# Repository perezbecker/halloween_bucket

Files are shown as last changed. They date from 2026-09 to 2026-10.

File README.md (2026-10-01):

# Cyclops Cauldron

A 3D-printed Halloween candy bucket with a sculpted skull, an animated
HalloWing eye behind a glass lens, and a rope handle. The skull prints
separately in white or glow PLA; the electronics sit behind a removable
battery cradle and candy guard.

The project includes parametric CAD, STEP and STL exports, editable print
plates, assembly illustrations, and audited G-code for a **Prusa CORE One+**.
All parts can be printed with a single nozzle and assembled with screws.

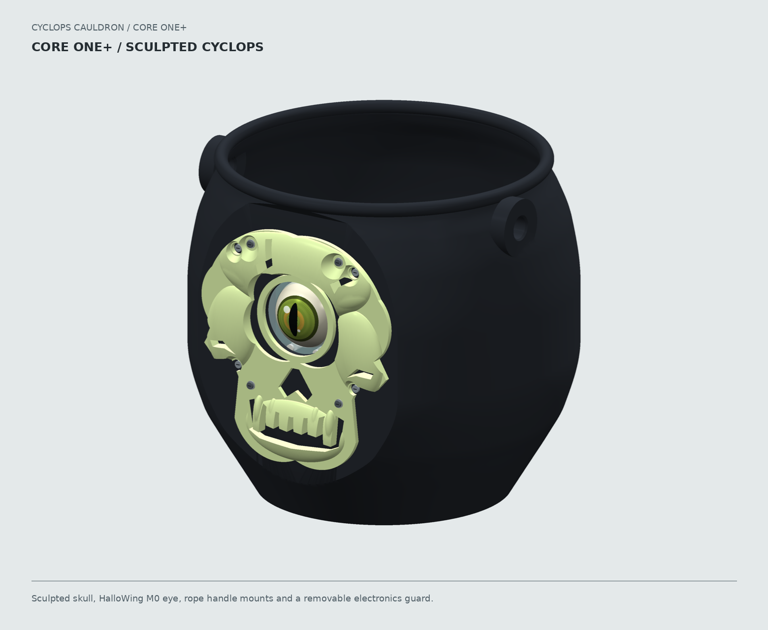
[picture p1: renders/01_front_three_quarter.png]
Assembled Cyclops Cauldron


**Build status:** the printed design has been reported to assemble and work
successfully. CAD and slicing checks also pass. Each builder should still
check their hardware fit and carrying strength; there is no certified load
rating or impact-resistance claim.

## Start Here

1. **Gather the hardware.** Use a HalloWing **M0**, its lens kit, and the
   fasteners in the [hardware list](docs/ASSEMBLY.md#hardware-list).
2. **Check your printer setup.** The supplied G-code requires the
   [CORE One+ configuration below](#printer-and-materials). For another setup,
   reslice the geometry with the appropriate printer and filament profiles.
3. **Print the small parts first.** Print the mounting test, one skull, and
   one carrier plus guard. The carrier and guard can share a plate.
4. **Fit-test the electronics.** Follow the
   [illustrated assembly guide](docs/ASSEMBLY.md#illustrated-assembly-sequence)
   and [fit-test procedure](docs/ASSEMBLY.md#fit-test-first).
5. **Print the cauldron and finish the build.** Transfer the tested parts,
   attach the rope, and complete the [hanging checks](docs/ASSEMBLY.md#rope-balance).

The mounting test is a small section of the bucket wall. It lets you check
the screws, lens alignment, PCB clearance and guard before the full bucket
print. The skull, carrier, guard and electronics used in the test are reused
in the finished bucket.

## What You Need

- Conventional PLA for the body, carrier, guard and mounting test; white PLA
  or suitable glow-in-the-dark PLA for the skull.
- Adafruit **HalloWing M0 #3900**, **40 mm glass lens #3853**, and
  **acrylic lens-holder kit #4013**.
- Adafruit **3.7 V, 500 mAh LiPo #1578**, a soft insulating pad and a
  hook-and-loop battery strap.
- **Eight M2 x 20**, **four M2 x 10**, and **four M2.5 x 20** machine screws,
  **12 M2 nuts**, **12 M2 washers**, and **four M2.5 insulating washers**.
  Keep the kit's four front M2.5 x 5 screws.
- Approximately **8-10 mm nylon sail rope** for the handle.

See the [complete bill of materials](docs/ASSEMBLY.md#hardware-list) for
washer dimensions, nut sizes and the purpose of each fastener. **M2 and M2.5
are different threads:** the bucket mounts use M2; the lens kit uses M2.5.

The eye runs on the HalloWing. This repository supplies the mechanical build,
not custom firmware; use the [electronics setup instructions](docs/ASSEMBLY.md#prepare-the-eye-electronics)
to check the eye demo before installing the board.

## Printer And Materials

Use the supplied G-code only when your setup matches:

| Requirement | Supplied configuration |
| --- | --- |
| Printer | Prusa CORE One+, single tool, without MMU or INDX |
| Nozzle | **0.4 mm high-flow**; wear-resistant/hardened for glow PLA |
| Filament | **1.75 mm PLA**, suitable for 220 C first layer / 215 C thereafter |
| Sheet / bed | Clean smooth PEI suitable for PLA, **60 C** |
| Firmware | Compatible with the official COREONE profile; jobs include notice **6.8.1+16182** |

Do not bypass printer or nozzle warnings. Standard-flow or different-diameter
nozzles, other printers, and other materials require reslicing. **Glow PETG is
not glow PLA** and must not use these files. Ordinary white PLA does not
require the glow job's abrasive-material setting.

Read the [printing guide](docs/PRINTING.md) and
[USB checklist](usb/COREONE_04HF_PLA/START_HERE.txt) before starting.

## Choose Your Print Jobs

For one complete build, choose **one skull material** and **one way to print
the carrier and guard**. Do not print both alternatives unless you want spares.

| Part or plate | G-code | Filament estimate | Time estimate |
| --- | --- | ---: | ---: |
| Mounting test | [01 Test](usb/COREONE_04HF_PLA/01_test_BLACK_04HF_PLA.gcode) | 37.27 g PLA | 1 h 47 m |
| Skull: white option | [02 White skull](usb/COREONE_04HF_PLA/02_skull_WHITE_04HF_PLA.gcode) | 64.17 g PLA | 4 h 52 m |
| Skull: glow option | [02 Glow skull](usb/COREONE_04HF_PLA/02_skull_GLOW_04HF_PLA.gcode) | 98.72 g glow PLA | 5 h 40 m |
| Carrier and guard together | [03+04 Combined](usb/COREONE_04HF_PLA/03_04_carrier_guard_BLACK_04HF_PLA.gcode) | 109.53 g PLA | 5 h 17 m |
| Carrier only | [03 Carrier](usb/COREONE_04HF_PLA/03_carrier_BLACK_04HF_PLA.gcode) | 26.20 g PLA | 1 h 32 m |
| Guard only | [04 Guard](usb/COREONE_04HF_PLA/04_guard_BLACK_04HF_PLA.gcode) | 83.38 g PLA | 3 h 44 m |
| Full bucket, after fit testing | [05 Cauldron](usb/COREONE_04HF_PLA/05_cauldron_BLACK_04HF_PLA.gcode) | 622.99 g PLA | 26 h 22 m |

The combined plate prints both parts **layer-by-layer**, not one complete
object at a time. It contains exactly the same carrier and guard as the
individual jobs. All jobs use one filament on extruder 1, with no purge tower
or mid-print colour changes.

With the combined plate, budget approximately **769.79 g for the body,
mounting test, carrier and guard**, plus **64.17 g white** or **98.72 g glow**
for the skull. Separate carrier/guard jobs bring the first total to 769.84 g.
These are slicer estimates including automatic startup purge, not measured
print weights. Leave extra filament for loading, retries and spares.

## Assembly

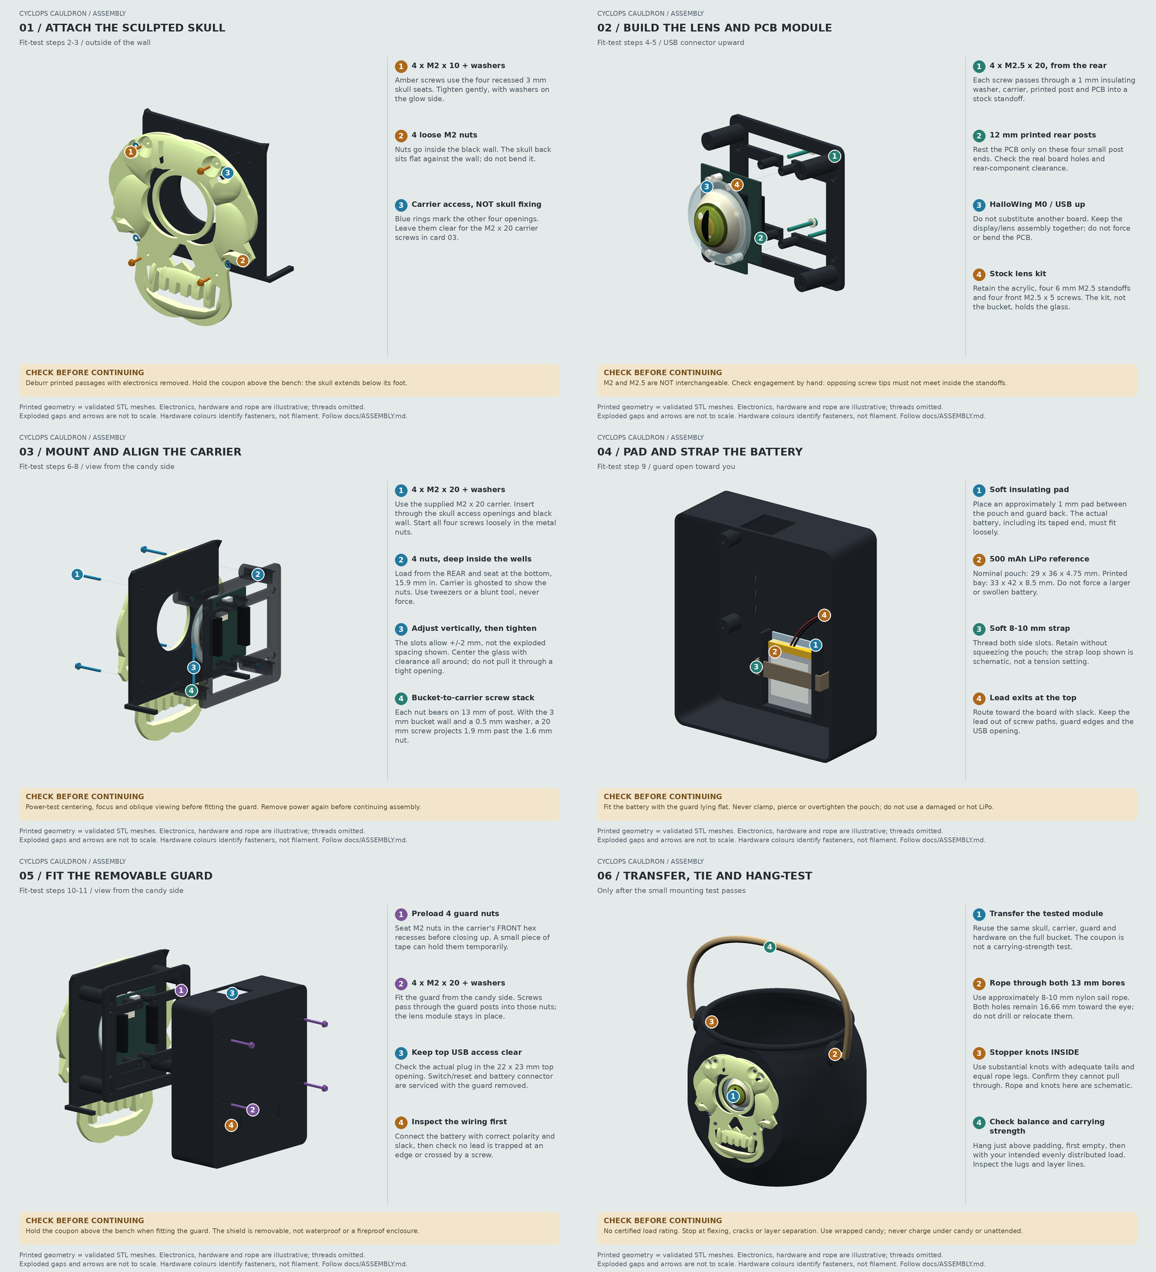
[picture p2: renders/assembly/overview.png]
Six illustrated assembly stages


The [assembly guide](docs/ASSEMBLY.md) covers mounting the skull, assembling
the lens/PCB module, aligning the carrier, securing the battery, fitting the
guard and attaching the rope.

- The skull attaches with **four M2 x 10 screws** and outside washers.
- The carrier attaches with **four M2 x 20 screws**. Seat its nuts at the
  bottoms of the **15.9 mm deep rear rectangular wells**, not at the openings.
- The PCB/lens module uses **four M2.5 x 20 screws with 1 mm insulating washers**.
  The stock acrylic kit retains the glass; the printed bezel does not clamp it.
- The guard attaches with the other **four M2 x 20 screws** and can be removed
  for battery and electronics access.

Use wrapped candy or a suitable liner. Check rope knots and printed anchors
over a padded surface before carrying a load. Protect the glass from impacts,
keep the electronics dry, and charge the LiPo under supervision with the
bucket empty and the guard removed. See [safe use and servicing](docs/ASSEMBLY.md#final-assembly-and-use).

## Design At A Glance

| Feature | Dimension |
| --- | --- |
| Printed body envelope | **224 x 209 x 200 mm** |
| Walls / floor | **3 mm nominal / 3.6 mm** |
| Rim / rope anchors | **8 mm rolled lip / 10 mm thick anchors** |
| Rope holes | **13 mm**, positioned toward the electronics |
| Sculpted skull | Approximately **128 x 138 mm**, up to **10.5 mm** thick |
| Skull screw seats / eye opening | **3 mm / 44.4 mm** |
| PCB rear-component clearance | **12 mm**, with **+/-2 mm** vertical eye adjustment |
| Battery bay | **33 x 42 x 8.5 mm** |

Explore the [design overview](renders/overview.png),
[exploded assembly](renders/07_exploded_mount.png),
[skull details](renders/faceplate_overview.png) and
[individual print-bed previews](renders/print_beds/overview.png).
Renders use the exported print meshes. Electronics, fasteners and optics are
illustrative; the green skull and glow study are not brightness predictions
or representations of white PLA.

## Editable Files And Project Layout

| Location | Contents |
| --- | --- |
| [print/](print/) | STL parts and placed geometry 3MFs, including the [combined carrier/guard plate](print/03_04_carrier_guard_black.3mf) |
| [cad/](cad/) | Individual STEP solids and the [assembled bucket](cad/assembled_bucket.step) |
| [design/](design/) | Parametric [bucket and mounting design](design/bucket.py) and [sculpted faceplate](design/sculpted_faceplate.py) |
| [usb/COREONE_04HF_PLA/](usb/COREONE_04HF_PLA/) | Ready-to-print jobs for the documented printer setup |
| [profiles/](profiles/) | Slicer settings and pinned profile provenance |
| [docs/](docs/) | Printing, assembly, mechanical sources and validation reports |
| [renders/](renders/) | Design views, assembly cards and print-bed illustrations |
| [tools/](tools/) and [tests/](tests/) | Export, slicing, rendering and validation tooling |

The skull geometry files use the name `bucket_glow` or
`02_skull_faceplate_glow.3mf`; **the same shape is used for white and glow PLA**.
Material selection belongs to the slicer profile. The geometry 3MFs can be
resliced for other supported setups; do not treat the supplied G-code as
printer-independent.

## Rebuild

You do not need the development tools to print the supplied jobs. For CAD,
slicer and render work, use Python 3.11 with the pinned
[dependencies](requirements.txt), CadQuery, PyVista/VTK and **PrusaSlicer 2.9.6**.
The rendering scripts use Linux DejaVu fonts. From the repository root on
Linux or WSL:

```sh
uv venv .venv --python 3.11
uv pip install --python .venv/bin/python -r requirements.txt
.venv/bin/python tools/build.py
.venv/bin/python tools/check_slicer.py --slicer /path/to/prusa-slicer-2.9.6
.venv/bin/python tools/check_slicer.py --white-skull --slicer /path/to/prusa-slicer-2.9.6
.venv/bin/python tools/check_slicer.py --carrier-guard --slicer /path/to/prusa-slicer-2.9.6
.venv/bin/python tools/render.py
.venv/bin/python tools/render_assembly.py
.venv/bin/python tools/render.py --print-beds
.venv/bin/python -m unittest discover -s tests
```

The build exports the carrier and assembled STEP, checks all parts, and
preserves the supplied body, skull, guard and coupon exports against
[pinned hashes](docs/printed_parts.json). The default slicer command
regenerates the individual carrier job and audits all five individual jobs;
the two flags generate the white skull and combined plate separately.
Render commands do not modify manufacturing files.

Each generated job is checked for native import, model bounds, tool
assignment, temperatures, flow, startup and shutdown. CAD checks cover solid
and mesh validity, mounting passages, collisions, clearances and material
budgets. These checks complement physical fitting; they do not certify
carrying strength, optical performance or every filament/printer combination.

See [mechanical sources and validation scope](docs/SOURCES.md) for dimensions,
assumptions, upstream credits and the detailed
[CAD](docs/validation.json), [individual-job](docs/slicer_validation.json),
[white-skull](docs/white_skull_validation.json) and
[combined-plate](docs/carrier_guard_validation.json) reports.

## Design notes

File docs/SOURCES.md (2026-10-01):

# Mechanical Sources And Assumptions

Checked against manufacturer pages and source files on **2026-09-25**.
Dimensions are millimeters. Source-derived dimensions are distinguished from
design clearances and unmeasured assembly assumptions.

This reference supports the [printing](PRINTING.md) and
[assembly](ASSEMBLY.md) guides. It explains where dimensions come from and
what the automated checks establish.

## Build Status And Validation Scope

The project owner has reported that the parts printed, assembled and worked
well. This is practical build feedback, not instrumented measurement of
material strength, optical performance or hardware tolerances.

The JSON validation reports record automated CAD, mesh, slicer and G-code
checks. Their limitations describe the scope of those runs; physical build
feedback is recorded here separately. No certified carrying-load rating,
impact rating or food-contact suitability is provided.

## Manufacturer References

| Part | Source facts used | Reference |
| --- | --- | --- |
| HalloWing M0, #3900 | Nominal 60 x 51 x 11 envelope; rear LiPo/USB ports; USB upward | [Guide](https://learn.adafruit.com/adafruit-hallowing/overview), [product](https://www.adafruit.com/product/3900), [downloads](https://learn.adafruit.com/adafruit-hallowing/downloads) |
| LiPo #1578 | 29 x 36 x 4.75; 102 mm lead; 500 mAh, 3.7 V nominal | [Adafruit battery](https://www.adafruit.com/product/1578) |
| Glass lens #3853 | 40 outer diameter, 37.5 inner/dome diameter, 16 height, 22 focal length; lip-edge retained by holder | [Adafruit lens](https://www.adafruit.com/product/3853) |
| Lens holder #4013 | 52.3 x 50 x 2.8 nominal; eight M2.5 x 5 screws and four M2.5 x 6 F-F spacers | [Adafruit kit](https://www.adafruit.com/product/4013) |
| Lens assembly | Acrylic and PCB joined by four nylon M2.5 spacers and eight screws | [Adafruit assembly guide](https://learn.adafruit.com/hallowing-all-seeing-skull/build-the-all-seeing-skull) |
| Prusa CORE One+ | 250 x 220 x 270 build volume; one nozzle without MMU/INDX | [Prusa CORE One+](https://www.prusa3d.com/product/prusa-core-one/) |

The battery listing notes a folded/taped cable-end change from June 2022. The
cradle therefore has more room than the nominal pouch dimensions and uses a
soft strap rather than a tight clip. Check your particular battery, including
its end seal and cable fold; the cavity is not permission to use a swollen cell.

## Verified Hole Geometry

Source repository: [Adafruit-Hallowing-M0-PCB](https://github.com/adafruit/Adafruit-Hallowing-M0-PCB),
pinned at commit `c0585b0672ce13e163b8da6ce9215ec600c63d64`.

The Eagle board contains two plain 2.54 mm lower lens holes at
`(X,Y) = (+/-8.89, -18.161)` and two plated 2.5 mm upper lens holes at
`(+/-8.89, +27.559)`. Thus the pitch is **17.78 x 45.72**. The two larger
3.175 mm lanyard holes at `(+/-17.145, +22.86)` are **not** used by this design.

The lens-holder Illustrator file is a PDF-compatible vector drawing. Reading
its actual hole subpaths gives the same 17.78 x 45.72 pitch. Its central lens
circle maps to approximately `Eagle Y = 3.082925`, which is **1.616075 mm below**
the four-hole pattern's midpoint. The model uses that center, with +/-2 mm
vertical adjustment through the bucket's separate M2 carrier fasteners.

The historical vector drawing's aperture is approximately **36 mm**, while the
current glass listing mentions a **38 mm mounting cutout**; its outside outline
also differs slightly from the current kit's nominal dimensions. Accordingly,
**this project does not recreate or replace the acrylic retainer**. It reuses
the purchased kit and provides a 44.4 mm clearance opening in the bucket for the
40 mm lens. Validate the actual kit revision on the coupon.

The manufacturer notes an October 2023 PCB silkscreen/connector update; the
published mechanical source is older. No claim is made that a later unmeasured
revision is mechanically identical. The M0 hardware must pass the fit test.

The structured measurements, source hashes, connector locations, and PCB outline
are recorded in [hardware_reference.json](hardware_reference.json). The original
board and acrylic design are by **Limor Fried/Ladyada for Adafruit Industries**;
their source repository publishes them under Creative Commons Attribution/Share-Alike.
See its [license](https://github.com/adafruit/Adafruit-Hallowing-M0-PCB/blob/master/license.txt).
The bucket and cyclops skull artwork are drawn for this project, not copied
from a third-party printable model. Manufacturer source files remain in an ignored cache,
not in the distributed manufacturing files.

To reproduce the source measurements from the repository root:

```sh
curl --fail --location --create-dirs 'https://raw.githubusercontent.com/adafruit/Adafruit-Hallowing-M0-PCB/c0585b0672ce13e163b8da6ce9215ec600c63d64/Adafruit%20Hallowing%20M0%20Express.brd' -o .cache/hallowing.brd
curl --fail --location --create-dirs 'https://raw.githubusercontent.com/adafruit/Adafruit-Hallowing-M0-PCB/c0585b0672ce13e163b8da6ce9215ec600c63d64/HalloWing%20Lens%20Holder.ai' -o .cache/lens-holder.ai
.venv/bin/python tools/inspect_hardware.py .cache/hallowing.brd --lens .cache/lens-holder.ai --output docs/hardware_reference.json
```

## Design Clearances And Checks

- PCB thickness **1.6**, rear support height **12**, and a **1 mm insulating
  washer** are stack-up assumptions/design choices. Confirm actual thicknesses,
  component heights, and that the opposing M2.5 screw tips do not bottom out.
- The assembly has generous lateral clearance for the approximately 52 mm
  acrylic, PCB, and rear headers. The USB top throat is **22 x 23**, not a
  manufacturer-specified USB plug envelope. Try your actual plug before printing
  the full bucket. The switch/reset require removing the candy guard.
- The glass's complete lip cross-section and assembled focal behavior were not
  measured. The hole clears its full outer diameter; the purchased kit sets the
  display-to-lens spacing. Do not interpret the textured render dome as an
  optical simulation.
- Printed M2 and M2.5 clearances are **2.4** and **2.9** respectively. Guard M2
  nut recesses allow approximately **4.3 across flats / 1.8 deep**. The four
  bucket-side sliding wells are **4.3 wide x 8.8 high x 15.9 deep**, open from
  the carrier rear. They place the nut bearing faces at
  Y = **-73**, leaving **13 mm** of post toward the wall. A **20 mm M2** screw,
  0.5 mm washer, 3 mm wall and 1.6 mm nut leave **1.9 mm** of tip beyond the
  nut, inside the well. These are FDM fit allowances and nominal hardware
  assumptions, not measured tolerances or a strength certification.
- Battery space is **33 W x 42 H x 8.5 D**. The cell requires a soft pad,
  noncompressive strap, lead slack, and inspection before each use.
- Rope anchors are modeled 10 thick around 13 bores, tied into the black wall
  below the rolled rim. Their common Y = -16.66 axis offsets the handle toward
  the electronics. The balance calculation reports tilt about that modeled
  axis. **No FEA, instrumented drop/creep results, or certified carrying-load
  rating** is provided. Evaluate printed layer adhesion and rope abrasion.
- Density limits of **1.30 g/cm3 black / 2.00 g/cm3 glow** are conservative
  budgeting assumptions, not specifications for an unspecified filament brand.
  Actual slicing and manufacturing still control spool use.

## Cauldron Balance Assumptions

The cauldron has a 224 mm belly, 200 mm height, 186 mm neck diameter,
8 mm rolled lip, and 146 mm flat base. The flat electronics face is at Y = -89
and the eye at Z = 125. The skull has raised forehead, brow, cheek, jaw and tooth
contours, up to **10.5 mm total thickness**, over a flat **3 mm mounting layer**.
Recessed 8.4 mm diameter screw-seat lands accept **M2 x 10** fasteners.
The eye bezel is flat inside a 52.4 mm diameter keep-clear zone, with a
44.4 mm bore and separate carrier-screw access holes. The body wall has full
thickness behind the skull except for the eye and fastener openings.

Nominal balancing uses black/glow densities of 1.24/1.50 g/cm3. PCB and battery
masses come from Adafruit; the glass is **estimated at 31 g** from its approximate
glass-cap envelope, not a measured product weight. The acrylic/kit (5 g), extra
carrier/guard fasteners (12 g), skull fasteners (3 g), strap/pad (3 g), and
component mass centers are estimates, not measured assembly weights.
See [assembly and balance](ASSEMBLY.md#rope-balance) for the complete assumptions,
centered-candy scenarios, density/lens sensitivity, and required hanging test.

For a glow skull, the computed nominal assembly mass is **864.9 g**, with a
center near (0, -19.44, 100.59). The bore centers are
(+/-99.33, -16.66, 178), giving about **2.1 degrees of empty forward tilt**.
Both lug material and removed hole material are included; the coupon and
discarded supports are excluded. A symmetric rope is assumed. Unequal knots,
an off-center grip and uneven candy are not modeled. A conventional white
skull has a different mass, so its balance must be checked on the actual build.

## Digital Verification

[validation.json](validation.json) records valid CAD solids, watertight,
consistently wound meshes, volumes, bed envelopes, nonintersecting material
volumes, mounting/candy-guard clearances, fastener passages, and the coupon's
identity to the corresponding cauldron geometry. The black body and separate
sculpted glow faceplate are individually connected, nonintersecting solids. Four
additional screw bores, washer-bearing lands, and clearance for internal M2
hardware are checked. The actual faceplate is reused for the black coupon test.
The saved cauldron, carrier and guard STEP files are checked directly for
faceplate intersections. The skull has a complete 3 mm mounting layer with
outward relief. [printed_parts.json](printed_parts.json) pins sixteen
compatibility-critical cauldron, skull, guard and coupon CAD, STL, 3MF and
G-code files. The default build regenerates the carrier and verifies and reuses
those supplied exports. The individual and combined plates contain the same
carrier. Checks cover its interfaces, nominal M2 x 20 engagement, nut bearing
area and insertion paths at the center and both ends of the +/-2 mm adjustment.

Mass calculations use adaptive, spline-span CAD integration and are checked
against fine triangle meshes for both volume and centroid agreement. The
cauldron profile uses local cubic segments to avoid unstable section Booleans
on a single long interpolated surface. Checks require the coupon to retain a
complete wall, clear rope bores on the fixed printed axis, uninterrupted lug bearing
rings, and support-critical bowl/neck slopes above 55 degrees.

The [individual-job report](slicer_validation.json) covers native
**PrusaSlicer 2.9.6** imports, per-object bounds and extruder **1 only** for the
five single-part plates. The [white-skull report](white_skull_validation.json)
and [combined-plate report](carrier_guard_validation.json) track their own
inputs and outputs. The combined job also verifies both parts' extrusion on
every shared layer, resolving the slicer's object IDs by their names.

The G-code audit examines executable commands as well as settings, checking
model/nozzle/firmware notices, cleaning, levelling, single-nozzle use, PLA
temperatures, flow, model-phase moves and heater shutdown. Four negative tests
inject an extra tool, an out-of-bed move, overtemperature and missing mesh
activation; all must be rejected. Regression tests cover object-order changes,
invalid layer sequences and ownership of the separate validation manifests.

## Official Machine Profile

Source: [PrusaSlicer-settings-prusa-fff](https://github.com/prusa3d/PrusaSlicer-settings-prusa-fff),
commit `65c5c8f1e1c3836f306119c49d717759cbc368db`, bundle **PrusaResearch 2.5.10**.
The [pinned bundle](https://raw.githubusercontent.com/prusa3d/PrusaSlicer-settings-prusa-fff/65c5c8f1e1c3836f306119c49d717759cbc368db/PrusaResearch/2.5.10.ini)
and [PrusaSlicer 2.9.6 release](https://github.com/prusa3d/PrusaSlicer/releases/tag/version_2.9.6)
are the reproducible inputs. The executable used here is the official portable
Windows 2.9.6 build through WSL interop. The scripts also accept a native 2.9.6
executable through `--slicer`.

Profiles are resolved from **Prusa CORE One HF0.4 nozzle**, **0.20mm STRUCTURAL
@COREONE 0.4**, and **Generic PLA @COREONE HF0.4**. The official `start_gcode`
and `end_gcode` are preserved byte-for-byte at the configuration level. The
printer script emits COREONE identification, 0.4 mm high-flow nozzle checks,
the 6.8.1+16182 firmware notice, cleaning, mesh probing, chamber control, purge,
and parking. The glow profile sets `filament_abrasive=1`, activating the
firmware's abrasive/nozzle check. The original startup purge intentionally uses
Y = -2.5; model-phase motion is separately checked against the 250 x 220 bed.

Derived base settings use seven walls, 0.20 mm layers, conservative 6/3 mm3/s
conventional/glow flow limits, and **220/215 C nozzle, 60 C bed** PLA temperatures.
The sculpted faceplate overrides layer height to **0.10 mm** (0.20 mm first),
uses **100% rectilinear** infill and ten top/bottom solid layers, without supports
or a brim. The white skull uses conventional PLA with a 6 mm3/s limit and no
abrasive-material flag; glow uses 3 mm3/s and the abrasive check. These are
documented operating requirements, not approval for every filament brand. Full
configuration files and input/output hashes are in
[profiles/provenance.json](../profiles/provenance.json). Prusa profile authors
and licensing remain with their source repositories.

The G-code targets the documented **CORE One+ / 0.4 mm high-flow / PLA /
smooth PEI** setup, with a wear-resistant nozzle additionally required for
glow. It is **not universal across CORE One+ configurations**. Each builder
must verify the setup and observe the print rather than bypassing warnings.
The export and audit tools do not connect to a printer or change its firmware.

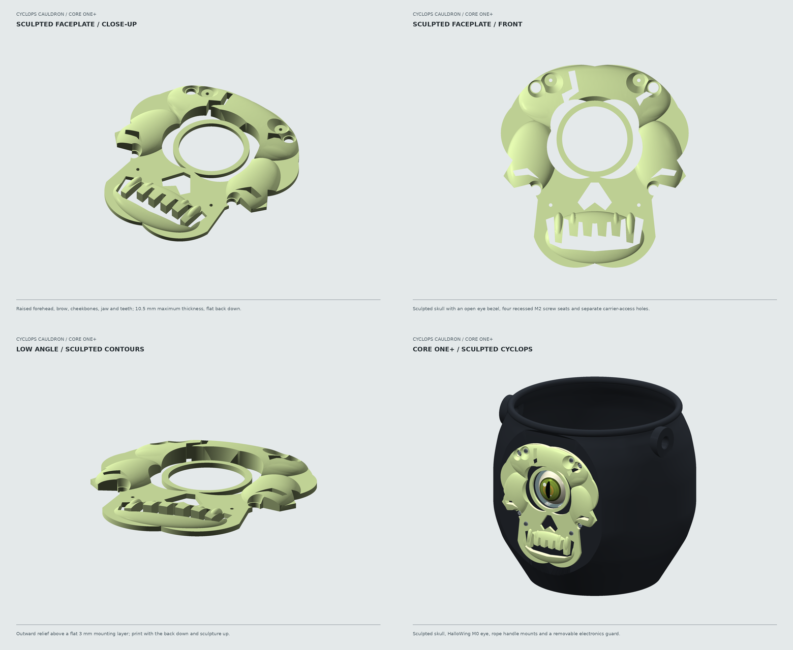
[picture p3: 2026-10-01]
renders/faceplate_overview.png

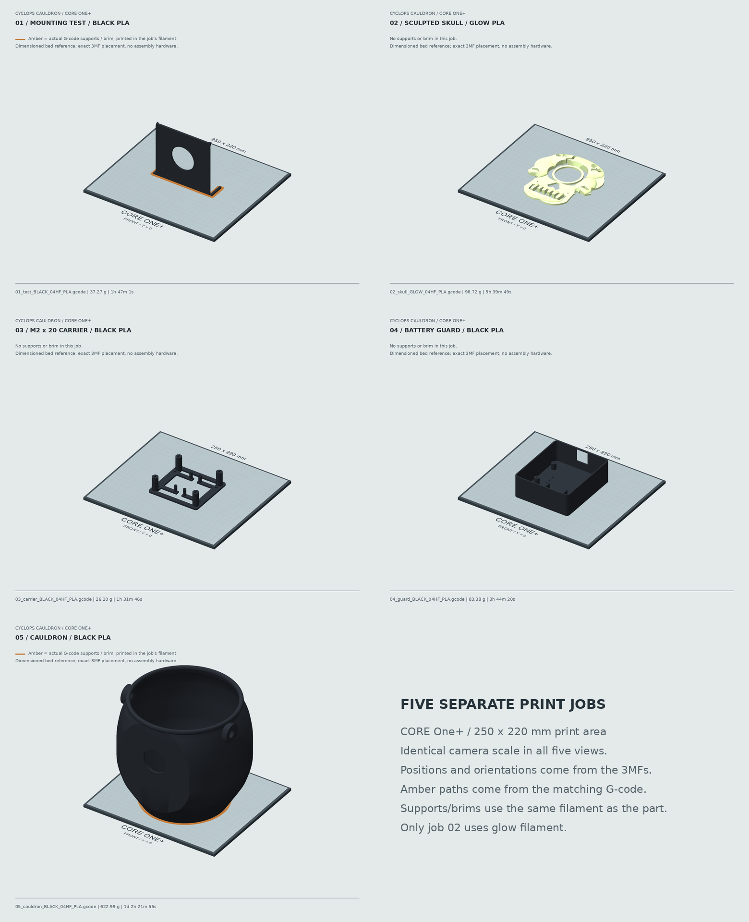
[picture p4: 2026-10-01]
renders/print_beds/overview.png

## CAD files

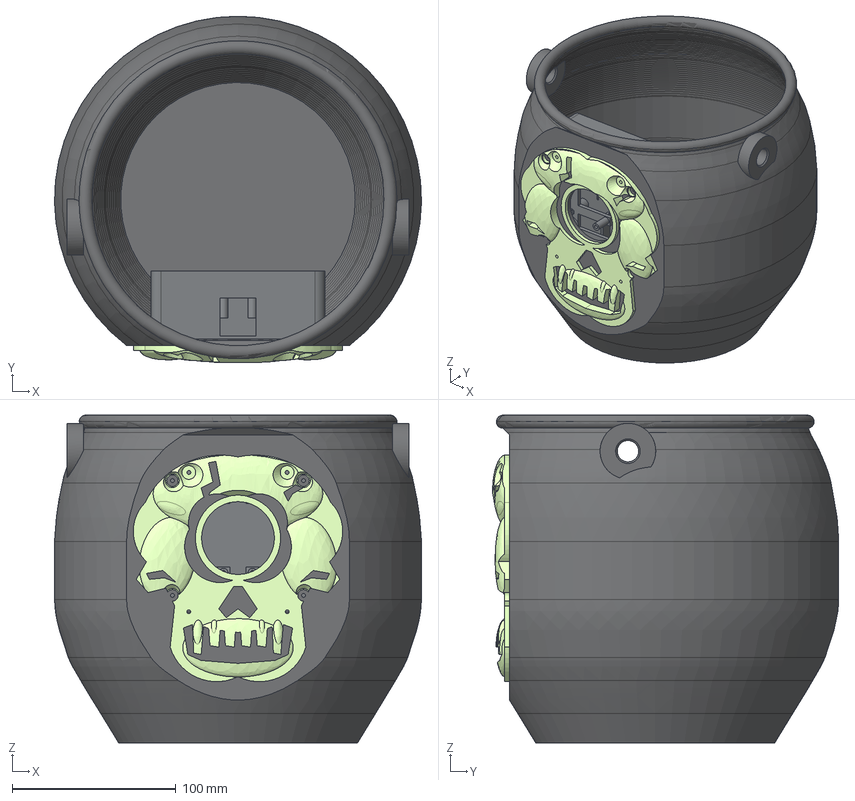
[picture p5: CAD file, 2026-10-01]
cad/assembled_bucket.step
224.0 x 211.5 x 200.0 mm
Bucket_black
Skull_glow
Carrier
Candy_guard

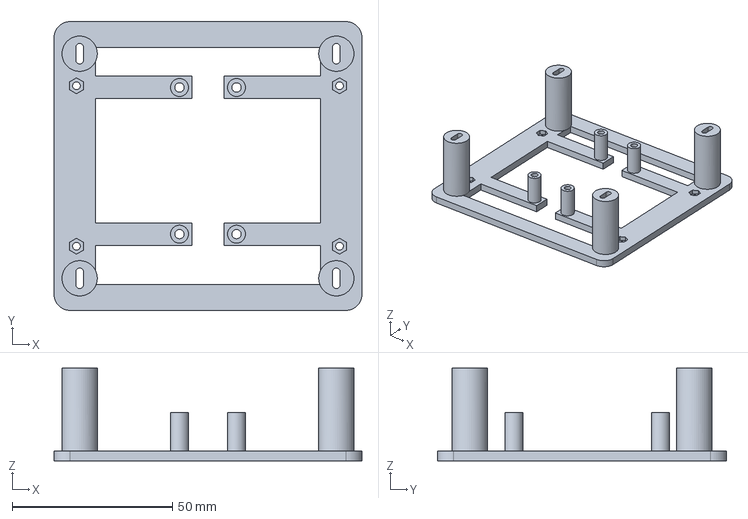
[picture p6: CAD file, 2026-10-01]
cad/carrier_black.step
96.0 x 90.0 x 28.9 mm

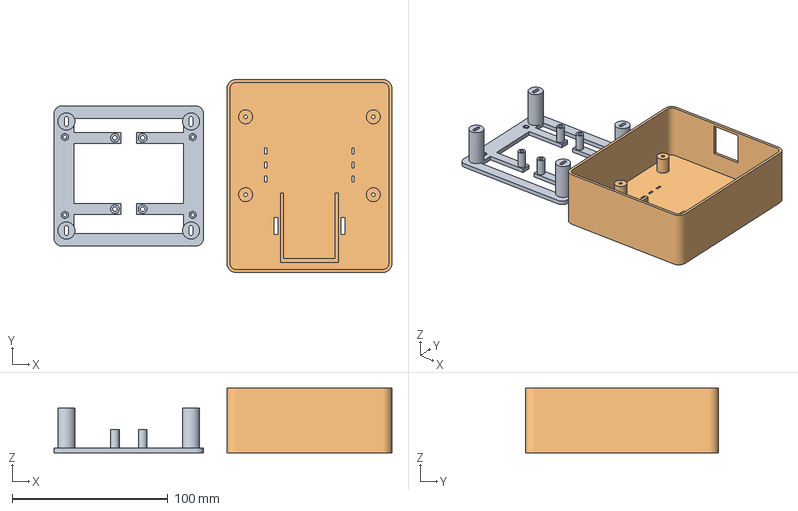
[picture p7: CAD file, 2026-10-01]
print/03_04_carrier_guard_black.3mf
217.0 x 124.0 x 41.5 mm
M2 x 20 carrier
Battery guard

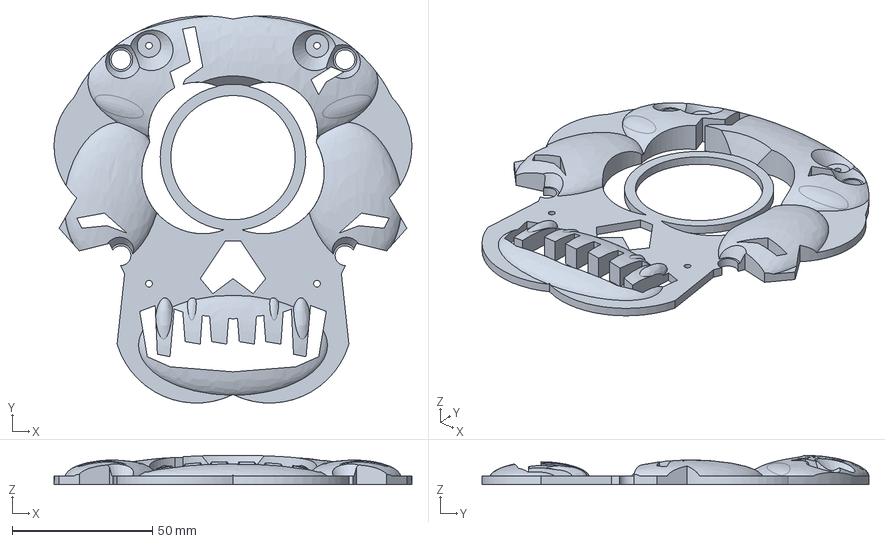
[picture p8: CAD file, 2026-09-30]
cad/bucket_glow.step
127.8 x 138.2 x 10.5 mm

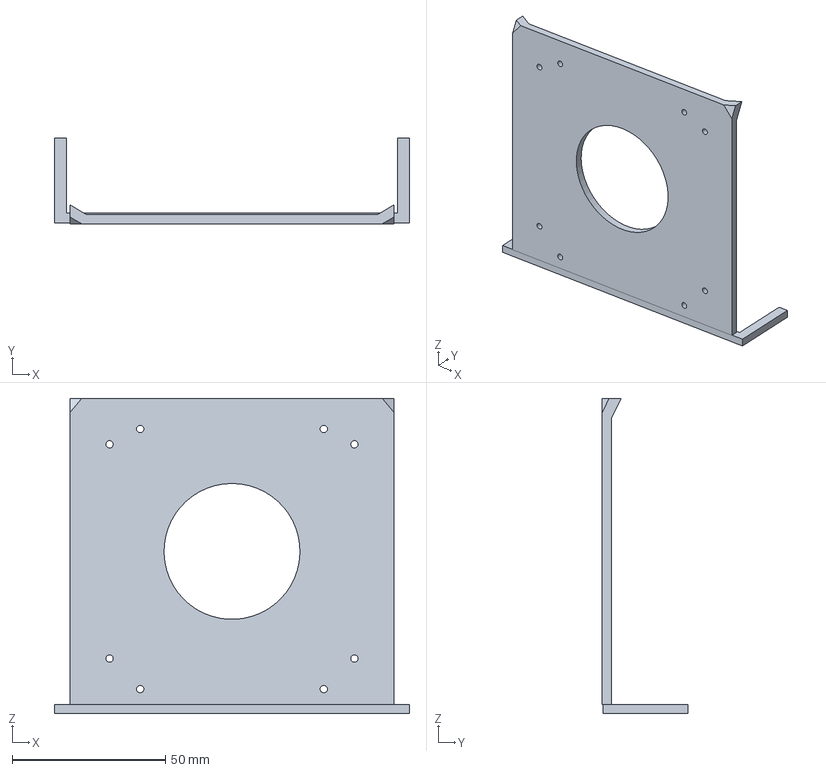
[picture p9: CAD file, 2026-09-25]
cad/test_black.step
116.0 x 28.0 x 103.0 mm

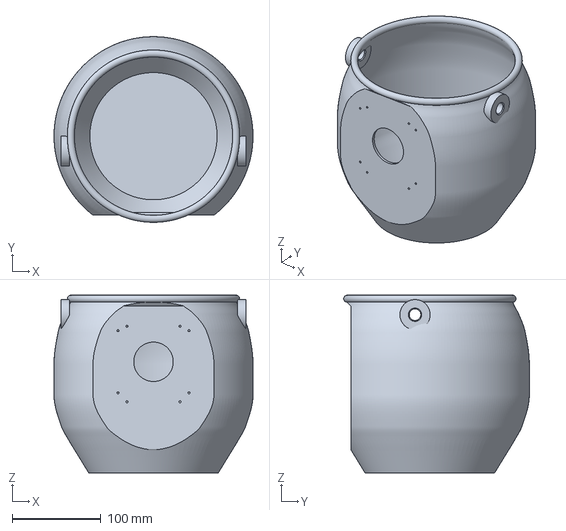
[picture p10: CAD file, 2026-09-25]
print/05_cauldron_black.3mf
224.0 x 209.0 x 200.0 mm

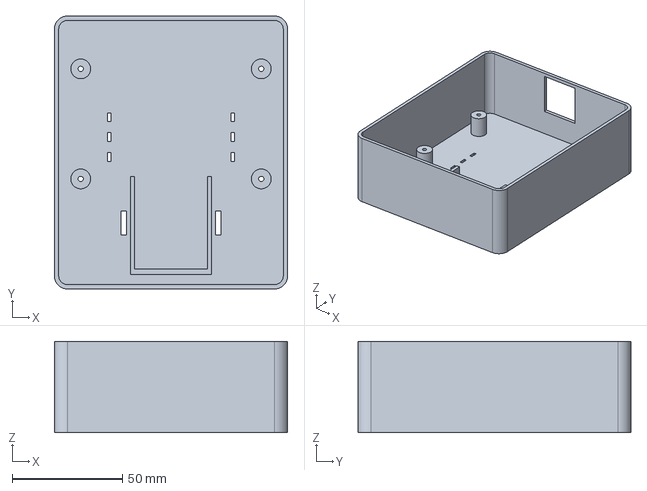
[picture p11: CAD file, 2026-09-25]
cad/guard_black.step
106.0 x 124.0 x 41.5 mm

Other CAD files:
print/03_carrier_black.3mf
print/02_skull_faceplate_glow.3mf
print/01_mount_test_black.3mf
cad/bucket_black.step
print/04_guard_black.3mf
print/bucket_glow.stl
print/carrier_black.stl
print/guard_black.stl
print/test_black.stl

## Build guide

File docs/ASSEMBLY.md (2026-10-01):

# Cyclops Cauldron Assembly

Assemble and test the small wall section before printing the full bucket.
The skull, carrier, guard and electronics from that test are reused in the
finished cauldron. White and glow skulls have identical geometry and hardware.

A completed build has been reported to work well. Printer tolerances and
hardware revisions can vary, so check your own parts rather than forcing a
fit. Use the HalloWing **M0**, not another board model.

[Hardware](#hardware-list) | [Illustrations](#illustrated-assembly-sequence) |
[Fit test](#fit-test-first) | [Final assembly](#final-assembly-and-use) |
[Mechanical reference](#mounting-datums)

## Hardware List

| Quantity | Item | Purpose |
| ---: | --- | --- |
| 1 | Adafruit #3900 HalloWing M0 | Eye display and controller |
| 1 | Adafruit #3853, 40 mm glass lens | Convex eye |
| 1 | Adafruit #4013 acrylic lens-holder kit | Acrylic, four 6 mm M2.5 F-F standoffs, and four front M2.5 x 5 screws |
| 1 | Adafruit #1578, 3.7 V 500 mAh LiPo | 29 x 36 x 4.75 mm nominal battery |
| 4 | **M2.5 x 20 mm** machine screws | Through the carrier, printed PCB posts and PCB into the kit standoffs |
| 4 | **1.0 mm thick M2.5 insulating washers**, outside diameter <=6 mm | Under the long rear screw heads, against the carrier |
| 4 | **M2 x 20 mm** machine screws | Bucket/coupon to carrier |
| 4 | **M2 x 20 mm** machine screws | Candy guard to carrier |
| 4 | **M2 x 10 mm** machine screws | Skull to the black wall |
| 12 | M2 hex nuts, approximately 4 mm across flats and 1.6 mm thick | Eight in carrier recesses; four loose inside the wall for the skull |
| 12 | M2 washers, approximately 0.5 mm thick, outside diameter <=5.5 mm | Spread head loads on the bucket, guard and skull |
| 1 | Soft hook-and-loop strap, 8-10 mm wide and <=2 mm thick, about 120 mm long | Loosely retain the battery through the guard slots |
| 1 | Thin, soft, electrically insulating pad, approximately 1 mm thick | Cushion the battery against the guard back |
| As needed | Nylon sail rope, approximately 8-10 mm diameter | Handle with two stopper knots inside the pail |

Total separate screws: **eight M2 x 20**, **four M2 x 10**, and **four M2.5 x 20**.
Keep the kit's four front M2.5 x 5 screws; its short rear screws are not used
through the printed carrier.

**M2 and M2.5 are different threads.** Do not substitute M2 screws in the
lens-kit standoffs. Prefer nonconductive hardware around the PCB. If using
metal screws, check clearances from components and exposed conductors.
Do not use pointed self-tapping screws, drill the PCB, or force screws into
printed plastic.

## Prepare The Eye Electronics

This project supplies the mechanical housing, not custom firmware. The
[Adafruit HalloWing M0 guide](https://learn.adafruit.com/adafruit-hallowing/overview)
describes the board and its default spooky-eye demo. Check that the board
powers up and displays the eye before installing it; use Adafruit's M0
documentation if it needs software setup or troubleshooting.

Keep the USB connector pointing upward. Use the purchased acrylic lens
holder, its four **6 mm M2.5 standoffs**, and four **front M2.5 x 5 screws**.
The acrylic kit retains the glass lip; **the printed eye opening does not
press-fit, clamp or support the glass**.

Disconnect power before mechanical work. Use the intended LiPo connection,
verify polarity, and keep the battery away from tools and screw paths.
The repository's USB G-code files are for the 3D printer, not the HalloWing.

## Illustrated Assembly Sequence

The six cards correspond to the detailed fit-test steps below. Open an image
for its full-resolution numbered callouts. Printed parts come from the STL
meshes; electronics, fasteners, strap, rope and optics are illustrative.
Exploded gaps and arrows are not to scale. Hardware colours distinguish screw
groups, not print materials. The illustrations show a glow-coloured skull;
the white version assembles the same way.

Six assembly cards

### 1. Skull To Test Wall

Four **M2 x 10 screws**, outside washers and loose nuts inside the wall attach
the skull. Its other four large openings provide access to the carrier screws.

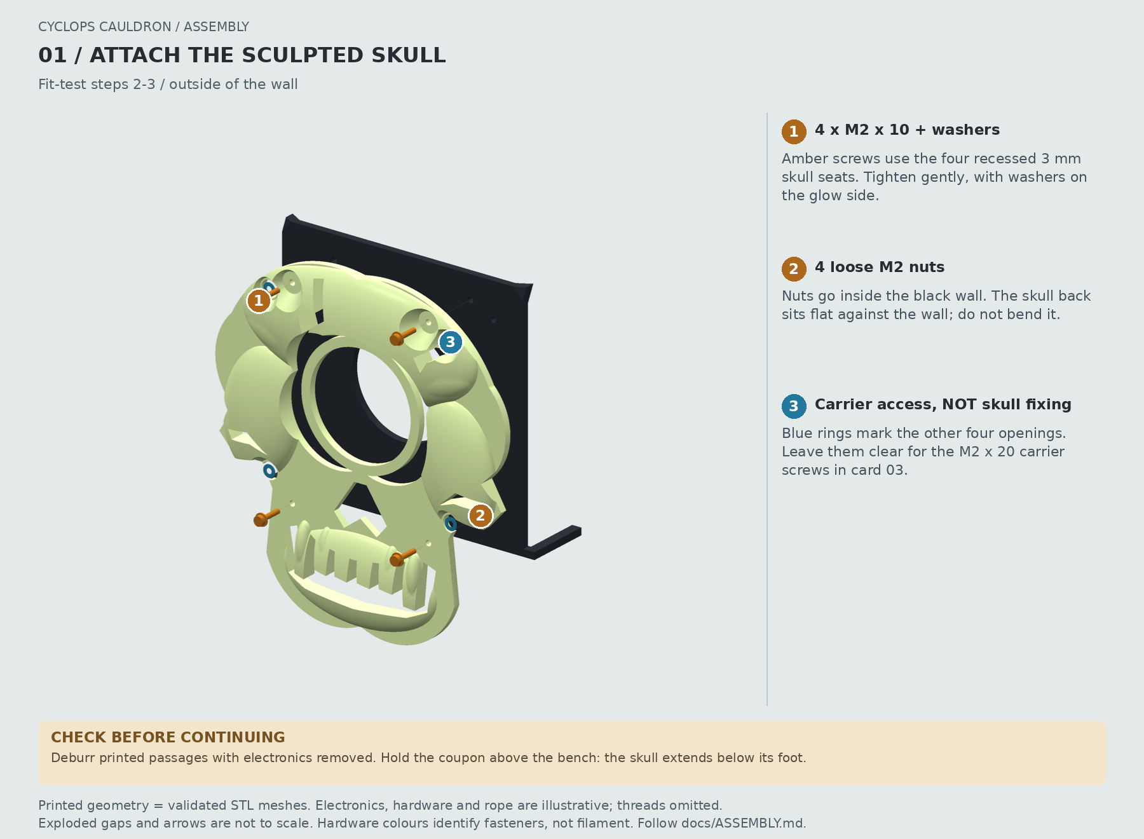
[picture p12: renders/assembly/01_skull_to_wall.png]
Attach the skull to the test wall


### 2. Lens, PCB And Carrier

Four **M2.5 x 20 screws with 1 mm insulating washers** pass through the carrier,
its PCB support posts and the PCB into the kit standoffs. Keep USB upward.

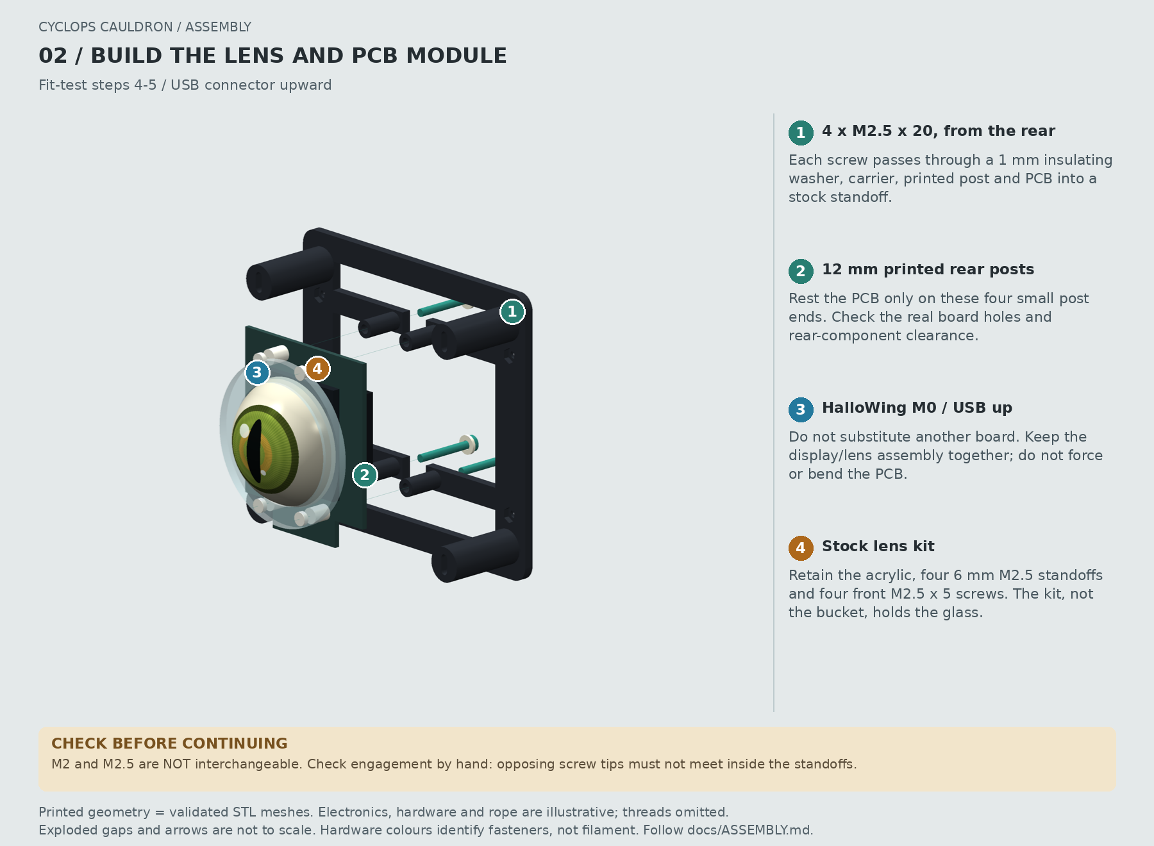
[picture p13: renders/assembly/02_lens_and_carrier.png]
Build the lens and PCB module


### 3. Carrier To Wall

Four **M2 x 20 screws** enter from outside. Seat their nuts at the bottoms of
the **15.9 mm deep rear rectangular wells**, not at the openings. Start loosely,
adjust eye alignment within +/-2 mm, and check glass clearance before tightening.

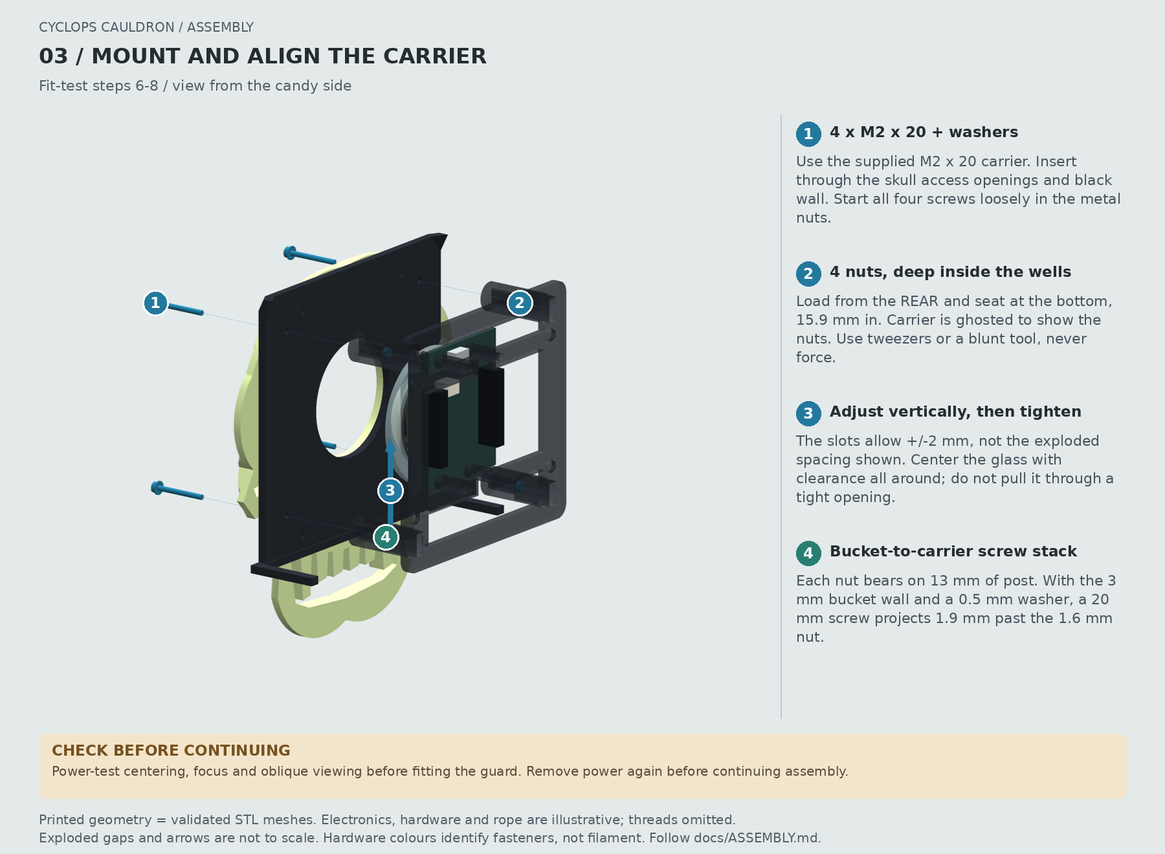
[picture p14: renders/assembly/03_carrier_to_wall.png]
Mount and align the carrier


### 4. Battery Pad And Strap

Fit the battery in the guard while it lies flat. Use the insulating pad and
soft strap through both slots; retain the pouch without squeezing it.

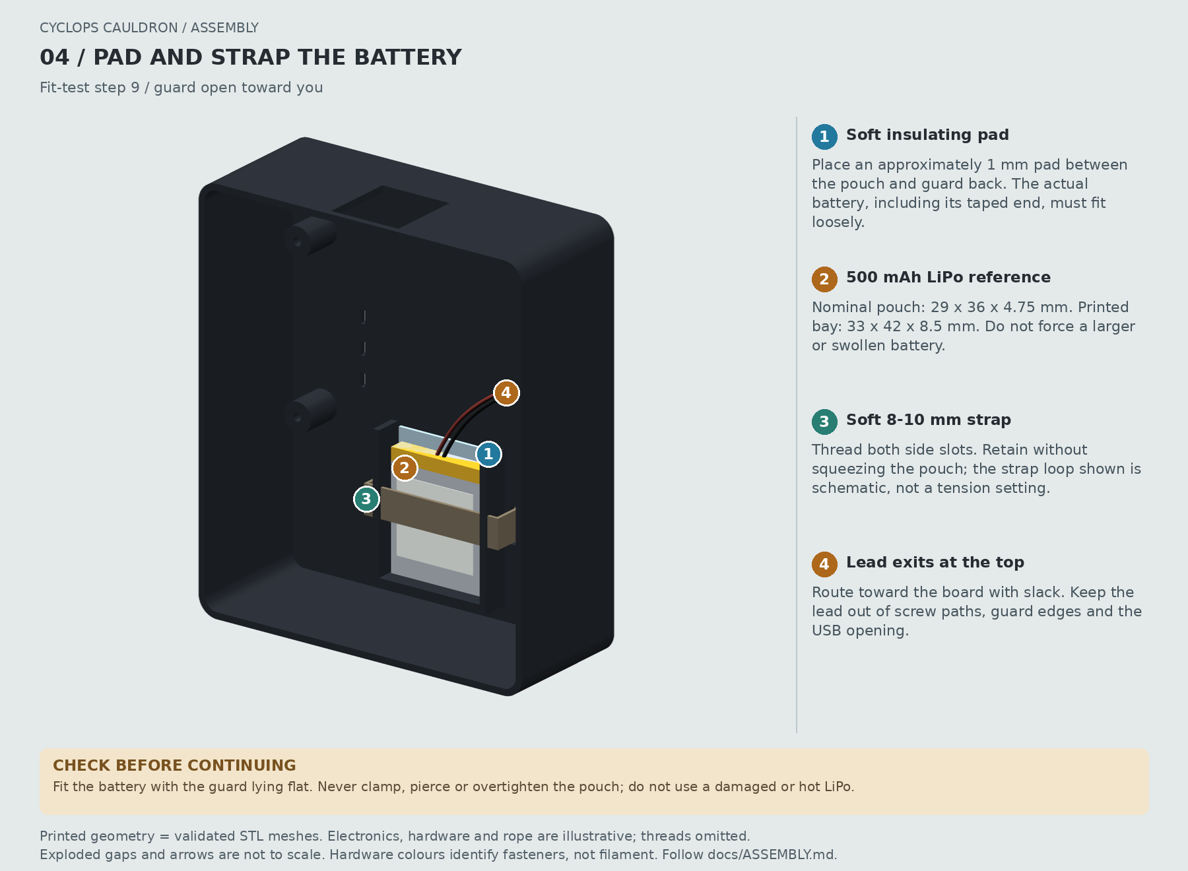
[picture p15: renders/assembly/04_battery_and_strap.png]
Pad and strap the battery


### 5. Removable Guard

Four nuts in the carrier's **front hex recesses** receive the guard's
**M2 x 20 screws and washers** from the candy side. Inspect wire routing and
USB access before closing the guard.

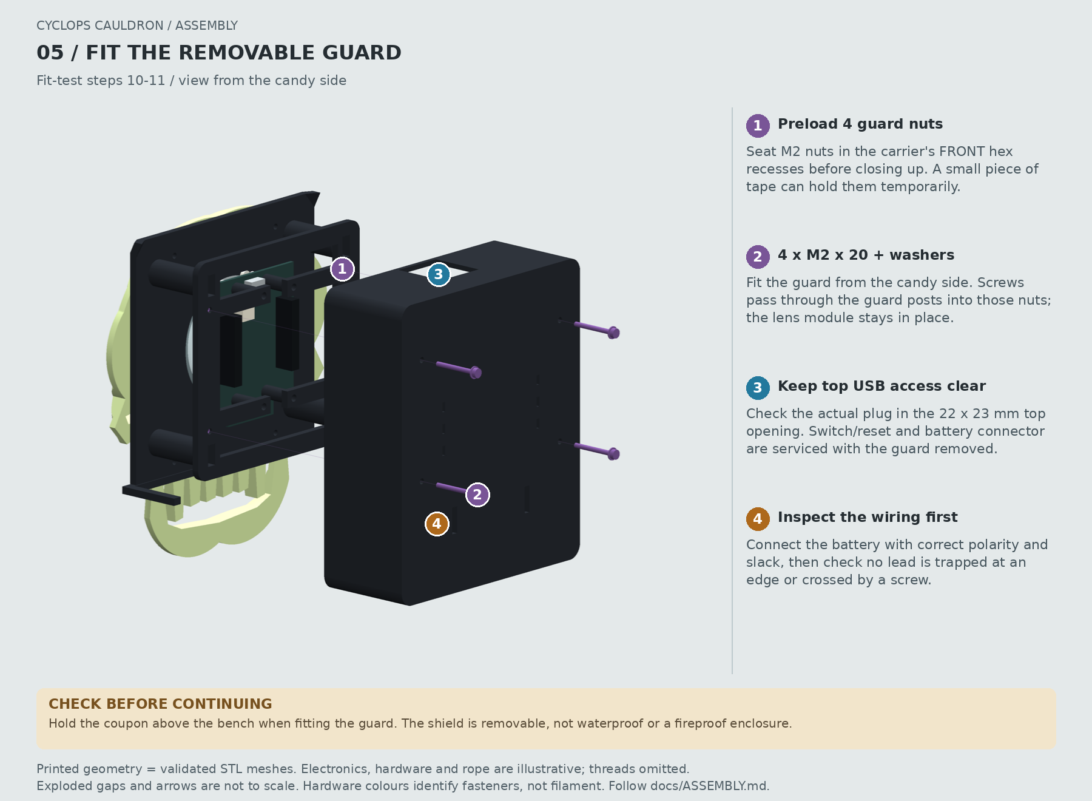
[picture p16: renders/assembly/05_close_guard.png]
Fit the removable guard


### 6. Transfer And Hanging Checks

Move the tested parts to the full cauldron, install the rope through its bores,
and secure substantial inside stopper knots with adequate tails. The knot
markers in the illustration are schematic, not knot-tying instructions.

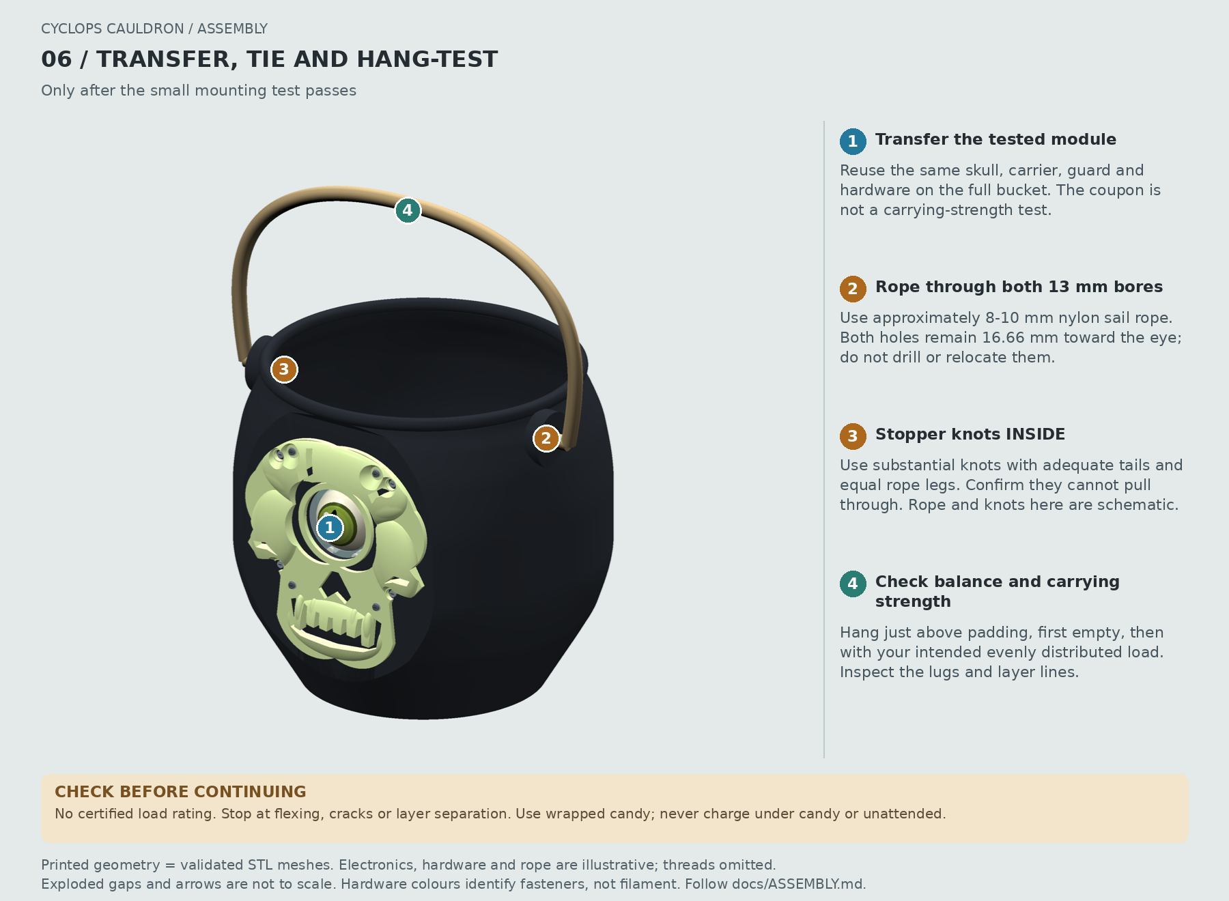
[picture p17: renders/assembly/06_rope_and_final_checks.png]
Transfer the parts and check the rope


## Fit Test First

1. Print [the test wall](../print/01_mount_test_black.3mf),
   [one skull](../print/02_skull_faceplate_glow.3mf), and
   [the combined carrier/guard plate](../print/03_04_carrier_guard_black.3mf)
   or the individual [carrier](../print/03_carrier_black.3mf) and
   [guard](../print/04_guard_black.3mf). Follow the material choices and
   printer prerequisites in [PRINTING.md](PRINTING.md).
2. Remove supports and burrs from the eye opening, mounting holes, nut wells
   and PCB support faces. M2 screws should pass freely through 2.4 mm passages,
   and M2.5 through 2.9 mm passages. Enlarge only printed plastic if necessary,
   with all electronics and the battery removed.
3. Attach the skull to the empty test wall with **four M2 x 10 screws**, washers
   on the skull side, and loose nuts inside the wall. The holes are at
   X = +/-30, Z = 80 and 165. Use the recessed **3 mm thick seats with 8.4 mm
   diameter lands**, not the larger carrier-access openings. Tighten gently
   until the flat back meets the wall without bending. A 0.5 mm washer,
   3 mm skull seat and 3 mm wall leave about 3.5 mm of screw for the nut and
   tip. Confirm real hardware lengths before installing electronics.
4. Check that all four PCB post centers match the real board without bending
   it, and that rear components clear the carrier. Stop if the board revision
   differs. Trial-fit the bucket screws and deep-well nuts before adding the
   PCB. Also preload the guard nuts into the front hex recesses; a small piece
   of tape can hold them temporarily.
5. Assemble the lens and acrylic with the stock standoffs and front M2.5 x 5
   screws. Rest the PCB on its four printed posts. From the rear, install the
   **four M2.5 x 20 screws and 1 mm insulating washers** through the carrier,
   posts and PCB into the standoffs. Check the [screw engagement](#side-stack)
   by hand, and tighten only enough to locate the board.
6. Seat four M2 nuts at the **bottoms of the 15.9 mm deep rear rectangular
   wells**. Their flats fit between the 4.3 mm wide side walls; the 8.8 mm
   height permits vertical adjustment. With the long posts pointing down,
   gravity, tweezers or a narrow blunt tool can help seat the nuts. Do not
   hammer them in. Loosely connect the carrier to the wall using
   **four M2 x 20 screws and 0.5 mm washers** from outside. All four should
   engage the metal nuts without bottoming or pulling the posts sideways.
7. Slide the carrier vertically until the eye is centered and the glass clears
   the printed opening all around. Check that the acrylic and its screw heads
   do not touch the wall. Do not use screws to pull glass through a tight hole.
8. Power the board and inspect eye centering, focus, oblique viewing and light
   leaks. The kit fixes the lens-to-display spacing; moving the carrier moves
   the complete module. Switch off and disconnect power before continuing.
9. Check that the battery sits loosely in the **33 x 42 x 8.5 mm bay**,
   including its folded/taped end and pad. Thread the strap through both
   **2.6 x 11 mm slots** and retain the battery without compressing the pouch.
10. Check that the four guard nuts are seated in the carrier's front hex
    recesses. Connect the battery with slack in its lead, then attach the
    guard from the candy side with **four M2 x 20 screws and washers**.
    No lead may cross a screw path or be trapped under an edge.
11. Check the USB plug through the **22 x 23 mm top opening** and confirm the
    guard can be removed without disturbing the lens. Access the battery
    connector, switch and reset button with the guard removed.

The coupon's foot supports the bare **wall + PCB + carrier** test. The full
skull and guard extend below it: hold the assembly above a padded surface or
bench edge while fitting them. Check the battery bay with the guard lying flat.
This small fixture is not a whole-bucket strength or balance test.

Record hole fit, glass clearance, acrylic thickness, alignment and battery
clearance before committing to the full print. Reuse these tested parts and
hardware in the finished bucket.

## Final Assembly And Use

Print the cauldron and follow the same assembly sequence on its front wall.
Deburr the two **13 mm rope holes**, thread the handle through them, and secure
substantial stopper knots inside. Leave adequate tails, check that the knots
cannot pull through, and use equal-length rope legs. No printed handle is
included.

Complete the [hanging check](#rope-balance) before use. There is **no certified
load rating**. After the empty check, begin with a **1 kg static test load**
just above a soft surface and inspect the bosses and layer lines. This is a
test procedure, not a rated capacity; establish suitability for the intended
contents with controlled testing. Stop at flexing, cracking or layer separation.
Do not swing a loaded bucket or use its rope as a neck strap.

Use wrapped candy or a removable food-safe liner. Printed PLA/glow filament
and layered FDM surfaces are not represented as food-contact safe. The guard
is a candy shield, not a sealed, waterproof, impact-proof or fireproof enclosure.
Protect the glass from impacts; it can break if dropped.

Switch off and empty the bucket before servicing. Charge under supervision in
an open, nonflammable location, preferably with the electronics removed and
guard off, never under candy. Do not use a swollen, damaged, crushed or hot
LiPo. Verify connector polarity, keep screw tips away from the pouch, and do
not overtighten the strap. Avoid heat, hot cars and rain.

## Rope Balance

Hang the empty assembly just above padding and check the rim from the front
and side. Repeat with the intended candy load distributed evenly. Inspect
the anchors and knots before carrying. Do not drill or elongate holes through
the thin body wall to alter balance.

The bore centers are **(-99.33, -16.66, 178)** and
**(+99.33, -16.66, 178)** mm: both are 16.66 mm toward the electronics from the
geometric centerline, at the same height.

The [balance model](validation.json) uses nominal densities of **1.24 g/cm3
black** and **1.50 g/cm3 glow**, CAD volume centroids, and hardware estimates:
17.5 g PCB, 10.5 g battery, 31 g glass, 5 g acrylic/lens hardware, 12 g
carrier/guard fasteners, 3 g skull fasteners and 3 g strap/pad. These are not
measurements of the completed build. They differ from the conservative
densities used for filament budgeting.

For a glow skull, the nominal assembled mass is **864.9 g**, with its center
near **(0, -19.44, 100.59)** mm, about **77.4 mm below** the rope axis.

| Centered candy load | Predicted pitch |
| --- | --- |
| Empty, electronics installed | 2.1 degrees toward the eye |
| 500 g | 2.7 degrees away from the eye |
| 1,000 g | 4.5 degrees away from the eye |

The payload model places candy at (0, 0, 65) mm. A fixed pair of holes cannot
keep the rim level for every fill. Varying black/glow density and glass mass
gives about -4.4 to -0.6 degrees of empty pitch; it does not bound uneven
packing, rope or all hardware differences. **White PLA changes the skull mass
and balance**, so use the physical hanging check for that build too.
Measured masses can be entered in the [parametric model](../design/bucket.py);
changing balance assumptions does not reposition the modeled rope holes.

## Mounting Datums

This reference is for checking hardware or editing the CAD. Units are
millimeters. Viewed from outside: X is right, Z is up, and the flat mounting
face is Y = -89. The eye center is X = 0, Z = 125. USB points upward.

| Feature | X coordinates | Z relative to eye center |
| --- | --- | --- |
| PCB/lens-kit upper mounting holes | -8.89, +8.89 | +24.476 |
| PCB/lens-kit lower mounting holes | -8.89, +8.89 | -21.244 |
| Bucket-to-carrier M2 fasteners | -40, +40 | -35, +35 |
| Guard-to-carrier M2 fasteners | -41, +41 | -25, +25 |
| Skull-to-wall M2 fasteners | -30, +30 | -45, +40 |

The stock kit uses the **17.78 x 45.72 mm** hole pattern, not the larger
lanyard holes. In the published drawing, the lens center is approximately
**1.616 mm below the mounting-pattern midpoint**. The carrier's slots provide
+/-2 mm of vertical adjustment for the actual lens/PCB fit.

## Side Stack

From outside to inside, excluding screw heads:

1. Skull back Y = -89; 3 mm seating layer and screw seats at Y = -92.
   Contours reach approximately Y = -99.5. The eye bezel is at Y = -92;
   the black wall spans Y = -89 to -86.
2. Stock lens/acrylic assembly: nominal acrylic front Y = -82.5, back Y = -79.7.
3. Stock **6 mm M2.5 F-F standoffs**, between acrylic and PCB front.
4. PCB front Y = -73.7, rear Y = -72.1; nominal thickness 1.6 mm.
5. **12 mm printed PCB posts**, touching the board only around mounting holes.
6. **3 mm carrier plate**, front Y = -60.1, rear Y = -57.1.
7. 1 mm insulating washers and M2.5 x 20 rear screw heads.
8. Free space, then guard inner back Y = -45.5, outer back Y = -43.5.

The bucket-to-carrier stack is **0.5 mm washer + 3 mm wall + 13 mm post before
the nut + 1.6 mm nut = 18.1 mm**. An M2 x 20 screw projects approximately
**1.9 mm beyond the nut**, inside its well. The nut's bearing plane is
Y = **-73.0**, 15.9 mm forward of the carrier rear. The skull's large access
holes let these screw heads bear on the black wall, so skull thickness is not
part of this stack.

The PCB/lens stack assumes 2.8 mm acrylic. Rear M2.5 screws engage about
**2.4 mm** and front screws about **2.2 mm** into each 6 mm standoff.
**Their tips must not meet.** Check real acrylic, washer and screw dimensions
by hand; adjust insulating washers or screw length if necessary. Never
tighten a bottomed-out screw to pull parts together.

The 40 mm lens has a nominal 16 mm overall height; its exact lip seating depth
was not measured. The stock holder retains the lip, and the bucket clears
the full lens diameter rather than assuming a precise glass profile. Expect
the dome to protrude a few millimeters beyond the bezel, depending on the kit.

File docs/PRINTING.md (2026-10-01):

# Printing The Cyclops Cauldron

The bucket has four installed printed parts: body, skull, electronics carrier
and battery/candy guard. A small mounting-test wall checks the assembly before
the full bucket print. All parts use one filament per job and one extruder.

The design has been printed and reported to work successfully. Use the
following setup checks for your own printer and material, even when printing
the supplied files.

## Material And Printer Setup

The [USB jobs](../usb/COREONE_04HF_PLA/) are ASCII G-code from **PrusaSlicer
2.9.6**, based on the official **Prusa CORE One HF0.4 nozzle** machine profile
and PrusaResearch bundle **2.5.10**. The COREONE profile is used for the
single-tool CORE One+.

| Requirement | Configuration |
| --- | --- |
| Printer | Stock Prusa CORE One+, one tool, no MMU or INDX |
| Nozzle | **0.4 mm high-flow** |
| Filament | **1.75 mm PLA**, rated for **220 C first layer / 215 C thereafter** |
| Sheet | Clean smooth PEI suitable for PLA |
| Bed | **60 C** |
| Chamber | Official automatic control, nominal **20 C**; keep vents unobstructed |
| Firmware | Compatible with the official profile; G-code includes notice **6.8.1+16182** |

For glow PLA, also use a **wear-resistant/hardened nozzle** and filament rated
for its 0.4 mm bore. Ordinary white or black PLA does not require the abrasive
filament check.

**Do not bypass printer/nozzle warnings.** A standard-flow or different-size
nozzle, different printer, sheet or material requires the appropriate profile
and reslicing. Glow PETG, including Prusament PETG Ultraglow, is not PLA and
must not use these jobs.

Official startup cleaning, probing, chamber control, purge and shutdown are
preserved. The startup cleaning/purge path intentionally uses Y = -2.5 before
layer 1. Model-phase moves are separately checked against the
**250 x 220 x 270 mm** build volume.

## Choose The Jobs

Print **one skull**, in either white or glow PLA. Print **one carrier and one
guard**, either together or in separate jobs. These are alternatives, not
additional parts.

| Part or plate | G-code | Material estimate | Time estimate |
| --- | --- | ---: | ---: |
| Mounting-test wall | [01 Test](../usb/COREONE_04HF_PLA/01_test_BLACK_04HF_PLA.gcode) | 37.27 g PLA | 1 h 47 m |
| White skull | [02 White](../usb/COREONE_04HF_PLA/02_skull_WHITE_04HF_PLA.gcode) | 64.17 g PLA | 4 h 52 m |
| Glow skull | [02 Glow](../usb/COREONE_04HF_PLA/02_skull_GLOW_04HF_PLA.gcode) | 98.72 g glow PLA | 5 h 40 m |
| Carrier and guard together | [03+04 Combined](../usb/COREONE_04HF_PLA/03_04_carrier_guard_BLACK_04HF_PLA.gcode) | 109.53 g PLA | 5 h 17 m |
| Carrier only | [03 Carrier](../usb/COREONE_04HF_PLA/03_carrier_BLACK_04HF_PLA.gcode) | 26.20 g PLA | 1 h 32 m |
| Guard only | [04 Guard](../usb/COREONE_04HF_PLA/04_guard_BLACK_04HF_PLA.gcode) | 83.38 g PLA | 3 h 44 m |
| Full bucket | [05 Cauldron](../usb/COREONE_04HF_PLA/05_cauldron_BLACK_04HF_PLA.gcode) | 622.99 g PLA | 26 h 22 m |

Print the small parts and complete the [fit test](ASSEMBLY.md#fit-test-first)
**before printing job 05**. Reuse the same skull, carrier and guard in the
full cauldron. You may group the conventional-PLA jobs to reduce filament swaps.
The `BLACK` and `WHITE` filenames describe the intended colours; conventional
PLA in another colour is usable if it meets the same material requirements.
The GLOW job has distinct flow and abrasive-filament settings.

### White PLA Skull

The white skull uses conventional, non-abrasive PLA with a **6 mm3/s flow
limit**. It prints flat-back-down with **0.10 mm layers**, a 0.20 mm first
layer, **100% rectilinear infill**, seven perimeters and ten top/bottom solid
layers, without supports or brim. It does not glow.

The [white profile](../profiles/core_one_plus_0.4HF_white_PLA.ini) and
[audit](white_skull_validation.json) record the settings, source geometry and
G-code hashes. The exact time estimate is **4 h 52 m 26 s**.

### Glow PLA Skull

The glow skull has the same geometry, mounting holes, orientation and layer
settings as the white version. Its profile limits flow to **3 mm3/s** and
enables the abrasive-filament nozzle check. The estimate is **5 h 39 m 49 s**.
Check your filament's nozzle-size and temperature requirements before use.

### Combined Carrier And Guard

The [combined plate](../print/03_04_carrier_guard_black.3mf) contains the same
**M2 x 20 carrier** and complete guard as the individual jobs, in their
back-down orientations. Both print from one spool in one colour.

There is **15 mm XY separation** and at least **16.5 mm bed-edge clearance**.
The printer alternates between the parts on each layer: **144 layers print
both**, followed by **63 guard-only layers**, for 207 total. Sequential-object
printing is disabled; do not enable it when reslicing this layout.

The estimate is **109.53 g / 84.25 cm3 / 5 h 16 m 43 s**. Have approximately
**130 g available** for margin. The [combined-job audit](carrier_guard_validation.json)
checks source meshes, placement, tool assignments and the actual per-layer
extrusion sequence. Do not also run jobs 03 and 04 unless you want spares.

## Print From USB

1. Check the configuration above and the
   [USB checklist](../usb/COREONE_04HF_PLA/START_HERE.txt).
2. Copy the selected `.gcode` files onto a readable FAT32 USB drive and safely
   eject it. Do not format a drive containing needed data. The printer runs
   G-code, not a zip archive or the STL/STEP/3MF source files.
3. Clear the entire sheet, load the appropriate PLA through the printer's
   filament menu, insert the drive and select the job.
4. Check printer/nozzle/material notices. Watch automatic cleaning, levelling
   and the first layer; on the combined plate, inspect both parts. Stop if
   material lifts or extrudes poorly.
5. Let the sheet cool, remove the part and loose material, then prepare for
   the next job. Change filament **between jobs**, never partway through one.

No electronics, glass, battery or rope belong in the printer during a job.
There are no mid-print colour changes or purge towers.

## Supplied Settings

| Setting | Body, test wall, carrier and guard | Skull, white or glow |
| --- | --- | --- |
| Layer / first layer | 0.20 / 0.20 mm | 0.10 / 0.20 mm |
| Wall / first-layer extrusion width | 0.45 / 0.50 mm | 0.45 / 0.50 mm |
| Perimeters | 7 | 7 |
| Top / bottom solid layers | 8 / 10 | 10 / 10 |
| Nominal infill | 15% gyroid | 100% rectilinear |
| Brim | 5 mm on bucket and test wall; none on carrier/guard | None |
| Supports | Automatic organic supports enabled for bucket/test wall; off for carrier/guard | Off |
| Flow limit | 6 mm3/s | 6 mm3/s white; 3 mm3/s glow |

The cauldron's **3 mm walls, 3.6 mm floor**, rim and anchors are modeled
geometry. Do not scale them down or use spiral vase mode.

Infill percentage applies only to space left after perimeters and solid
layers. In the supplied combined carrier/guard job, those paths fill the
printed sections: **there is no sparse internal-infill toolpath**, despite the
nominal 15% setting. Designed holes, nut wells and the guard cavity stay empty.

## Plate Order

Keep the supplied orientations when reslicing:

| Geometry plate | Orientation and purpose |
| --- | --- |
| [01 Mounting test](../print/01_mount_test_black.3mf) | 116 x 28 x 103 mm wall section, upright on its rear foot; tests wall holes in the bucket's print orientation |
| [02 Skull](../print/02_skull_faceplate_glow.3mf) | Approximately 128 x 138 mm, flat back down, sculpted face up; up to 10.5 mm thick with 3 mm screw seats |
| [03 Carrier](../print/03_carrier_black.3mf) | Flat back down, posts up; the 15.9 mm rear nut wells open toward the bed |
| [04 Guard](../print/04_guard_black.3mf) | Outer back down, walls and battery cradle up |
| [03+04 Combined](../print/03_04_carrier_guard_black.3mf) | Both parts in the same orientations, side by side |
| [05 Cauldron](../print/05_cauldron_black.3mf) | Upright on its flat base, mouth up; print after fitting the small parts |

The skull STL/3MF names contain `glow`, but the geometry is shared by both
materials. Each plate is one material on extruder 1. The combined plate has
two separate objects on that same extruder.

[Individual print-bed previews](../renders/print_beds/overview.png) show the
five single-part plates at a common scale. Amber lines are brim/support
toolpaths, printed in the part's filament, not a second colour.

## Support And Preview Checks

The eye bore, rope bosses and rolled lip may need local supports. The bucket
and test-wall presets enable automatic organic supports; actual paths depend
on the geometry and slicing. Keep support and interface material on extruder
1 and accessible for removal. Do not fill the carrier's nut wells with support.

Inspect these areas in the slicer preview and after printing:

- **Skull:** flat back at Z = 0; relief up to about Z = 10.5 mm. The eye
  opening and all screw passages must be clear.
- **Bucket:** continuous perimeters around the rim and rope anchors; no
  inaccessible support around the eye opening.
- **Carrier:** four **4.3 x 8.8 mm rectangular wells, 15.9 mm deep**, ending at
  the narrower screw slots. Clear strings and trial-fit nuts to the bottoms
  before installing electronics. Check the M2.5 PCB passages too.
- **Guard:** clear screw passages, strap slots and USB opening.

Short bridges at the nut-pocket transitions and strap slots require a
calibrated material profile. Remove supports and burrs from all PCB support
faces; never leave plastic remnants pressing against a component or the glass.

## Filament Planning

The totals below include one bucket, one test wall, one carrier and one guard.
Add **one** of the skull choices.

| Job selection | Conventional PLA for body/test/carrier/guard | White skull | Glow skull |
| --- | ---: | ---: | ---: |
| Combined carrier/guard | 769.79 g | 64.17 g | 98.72 g |
| Separate carrier and guard | 769.84 g | 64.17 g | 98.72 g |

Sliced weights use conservative densities of **1.30 g/cm3 conventional PLA**
and **2.00 g/cm3 glow PLA**. They include automatic startup purge and emitted
brim/support material, but not manual loading, retries or extra copies.
These are estimates, not measurements of a printed build.

For the separate-job glow configuration, the [CAD budget](validation.json)
allows **905.86 g conventional PLA** and **148.41 g glow**, including reserves
of 125 g and 50 g respectively. A 1 kg spool per material is the design
budget, not a reason to begin a job without enough usable filament left.
Do not reduce wall or anchor strength to make a nearly empty spool last.

## Reslicing And Verification

For a different setup, load a geometry 3MF into PrusaSlicer, select the correct
official printer/nozzle/material profiles, retain the orientations and
mechanical wall thicknesses, and inspect the preview. Ordinary PLA and glow
PLA profiles are not interchangeable with PETG or other materials.

The [black](../profiles/core_one_plus_0.4HF_black_PLA.ini),
[white](../profiles/core_one_plus_0.4HF_white_PLA.ini) and
[glow](../profiles/core_one_plus_0.4HF_glow_PLA.ini) profiles document the supplied
settings. See [rebuild commands](../README.md#rebuild) to reproduce the files.

The [individual-job](slicer_validation.json),
[white-skull](white_skull_validation.json) and
[combined-plate](carrier_guard_validation.json) reports cover native import,
dimensions, tool assignments, machine limits and output hashes. The automated
checks are not physical load, impact or filament-certification tests.

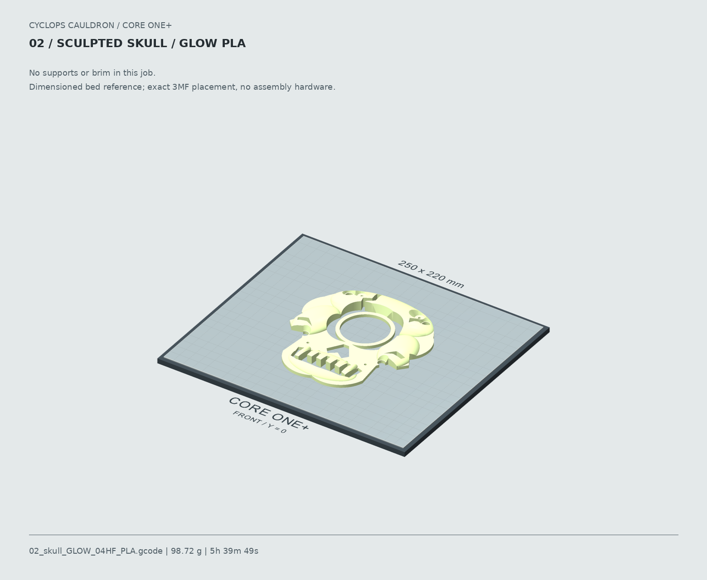
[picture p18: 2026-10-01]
renders/print_beds/02_skull_faceplate_glow.png

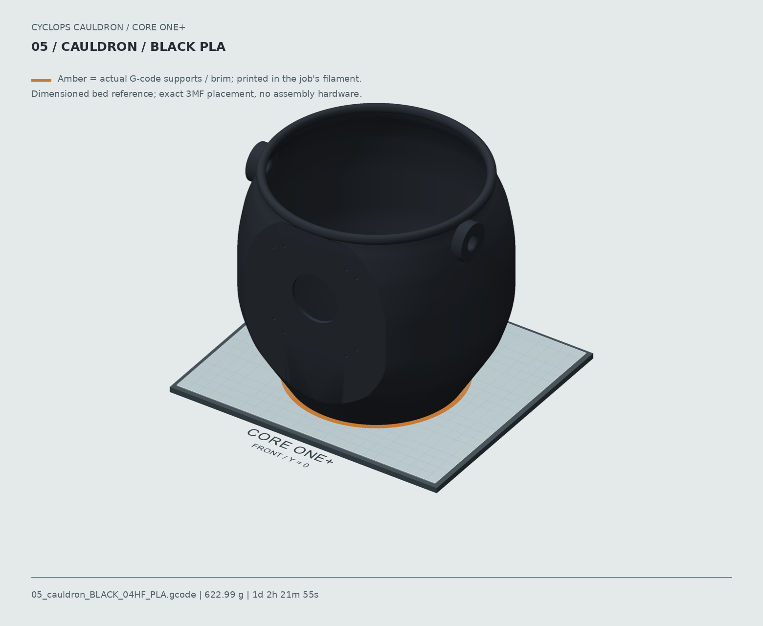
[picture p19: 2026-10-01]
renders/print_beds/05_cauldron_black.png

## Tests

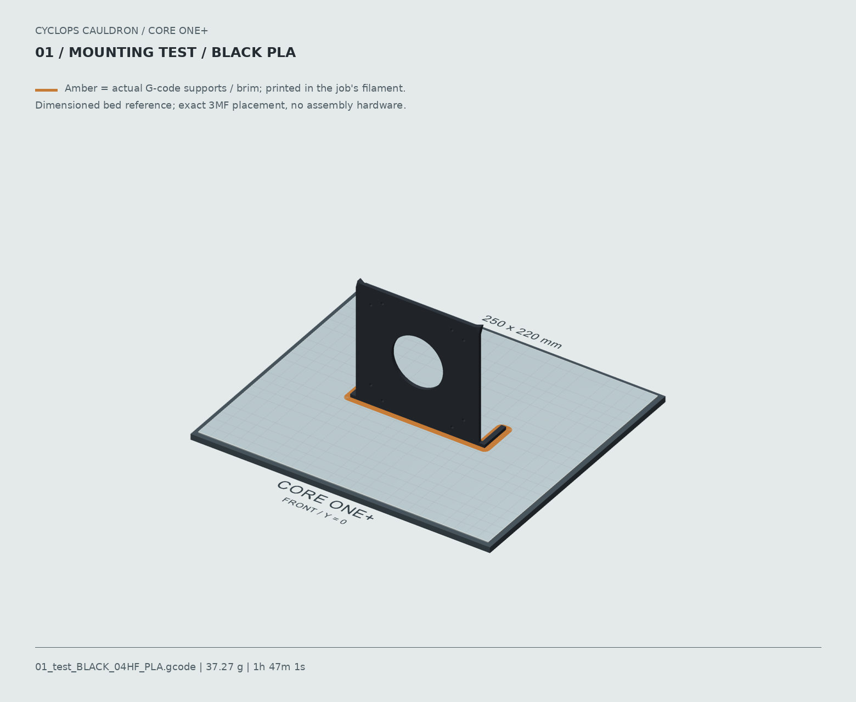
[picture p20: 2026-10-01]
renders/print_beds/01_mount_test_black.png

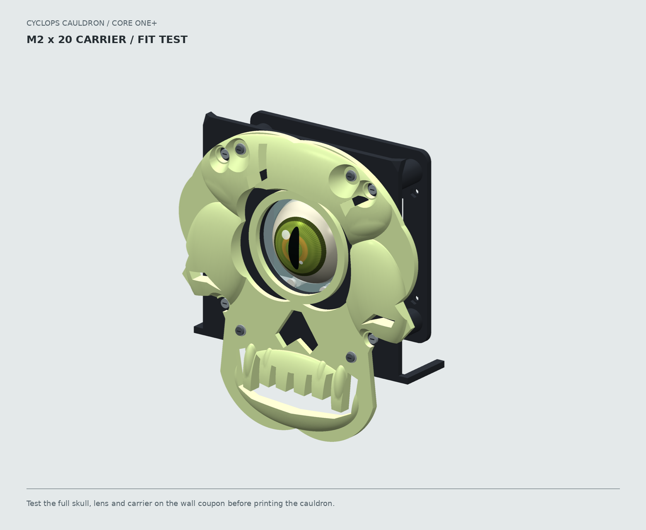
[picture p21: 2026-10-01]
renders/06_mounting_test.png

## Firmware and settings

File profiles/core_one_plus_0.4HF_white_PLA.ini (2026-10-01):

arc_fitting = disabled
bed_shape = 0x0,250x0,250x220,0x220
bed_temperature = 60
before_layer_gcode = ;BEFORE_LAYER_CHANGE\nG92 E0.0\n;[layer_z]\n{if layer_z > 150}\nM201 X{interpolate_table(layer_z, (0,7000), (150,7000), (200,4000), (270,2000))} Y{interpolate_table(layer_z, (0,7000), (150,7000), (200,4000), (270,2000))}\n{endif}\n
binary_gcode = 0
bottom_solid_layers = 10
bottom_solid_min_thickness = 0.5
bridge_acceleration = 1500
bridge_fan_speed = 100
bridge_flow_ratio = 1
bridge_speed = 50
brim_separation = 0.1
brim_width = 0
chamber_minimal_temperature = 0
chamber_temperature = 20
color_change_gcode = M600\nG1 E0.3 F1500 ; prime after color change
complete_objects = 0
cooling = 1
cooling_perimeter_transition_distance = 10
cooling_slowdown_logic = consistent_surface
cooling_tube_length = 20
cooling_tube_retraction = 45
default_acceleration = 3000
deretract_speed = 25
disable_fan_first_layers = 1
dont_support_bridges = 0
elefant_foot_compensation = 0.2
enable_dynamic_fan_speeds = 1
enable_dynamic_overhang_speeds = 1
end_filament_gcode = "; Filament-specific end gcode"
end_gcode = {if layer_z < max_print_height}G1 Z{z_offset+min(max_layer_z+1, max_print_height)} F720 ; Move print head up{endif}\nM104 S0 ; turn off temperature\nM140 S0 ; turn off heatbed\nM141 S0 ; disable chamber control\nM107 ; turn off fan\nG1 X242 Y211 F10200 ; park\nG4 ; wait\nM572 S0 ; reset PA\nM84 X Y E ; disable motors\n; max_layer_z = [max_layer_z]
external_perimeter_acceleration = 1500
external_perimeter_extrusion_width = 0.45
external_perimeter_speed = 50
external_perimeters_first = 0
extra_loading_move = -52
extra_perimeters = 0
extruder_clearance_height = 33
extruder_clearance_radius = 75
extruder_colour = ""
extruder_offset = 0x0
extrusion_multiplier = 1
extrusion_width = 0.45
fan_always_on = 1
fan_below_layer_time = 40
filament_abrasive = 0
filament_colour = #FFFFFF
filament_cooling_final_speed = 3.5
filament_cooling_initial_speed = 10
filament_cooling_moves = 2
filament_cost = 25.4
filament_density = 1.30
filament_diameter = 1.75
filament_infill_max_crossing_speed = 200
filament_infill_max_speed = 0
filament_load_time = 10.9
filament_loading_speed = 10
filament_loading_speed_start = 50
filament_max_volumetric_speed = 6
filament_minimal_purge_on_wipe_tower = 15
filament_notes = ""
filament_purge_multiplier = 81.25%
filament_ramming_parameters = "250 100 39.871 39.871| 0.05 39.9547 0.45 39.9547 0.95 39.9547 1.45 39.9547 1.95 39.9547 2.45 39.9547 2.95 39.9547 3.45 39.9547 3.95 39.9547 4.45 39.9547 4.95 39.9547"
filament_settings_id = Skull conventional white PLA 220-215C
filament_soluble = 0
filament_stamping_distance = 45
filament_stamping_loading_speed = 29
filament_toolchange_delay = 0
filament_travel_max_lift = 0.6
filament_travel_ramping_lift = 1
filament_travel_slope = 1
filament_type = PLA
filament_unload_time = 8.9
filament_unloading_speed = 40
filament_unloading_speed_start = 30
filament_vendor = Generic
fill_angle = 45
fill_density = 100%
fill_pattern = rectilinear
first_layer_acceleration = 500
first_layer_acceleration_over_raft = 0
first_layer_bed_temperature = 60
first_layer_extrusion_width = 0.50
first_layer_height = 0.20
first_layer_infill_speed = 100
first_layer_speed = 45
first_layer_speed_over_raft = 30
first_layer_temperature = 220
full_fan_speed_layer = 3
gap_fill_enabled = 1
gap_fill_speed = 60
gcode_comments = 0
gcode_flavor = marlin2
gcode_label_objects = firmware
gcode_resolution = 0.008
idle_temperature = 170
infill_acceleration = 6000
infill_anchor = 2
infill_anchor_max = 12
infill_every_layers = 1
infill_extruder = 1
infill_extrusion_width = 0.45
infill_first = 0
infill_overlap = 15%
infill_speed = 120
interface_shells = 0
ironing_type = top
layer_gcode = ;AFTER_LAYER_CHANGE\n;[layer_z]
layer_height = 0.10
machine_limits_usage = emit_to_gcode
machine_max_acceleration_e = 5000,2500
machine_max_acceleration_extruding = 7000,2500
machine_max_acceleration_retracting = 2500,2500
machine_max_acceleration_travel = 7000,2500
machine_max_acceleration_x = 10000,2500
machine_max_acceleration_y = 10000,2500
machine_max_acceleration_z = 400,200
machine_max_feedrate_e = 100,100
machine_max_feedrate_x = 350,160
machine_max_feedrate_y = 350,160
machine_max_feedrate_z = 12,12
machine_max_jerk_e = 10,10
machine_max_jerk_x = 10,8
machine_max_jerk_y = 10,8
machine_max_jerk_z = 2,2
machine_max_junction_deviation = 0.01,0.01
machine_min_extruding_rate = 0,0
machine_min_travel_rate = 0,0
max_fan_speed = 100
max_layer_height = 0.3
max_print_height = 270
max_print_speed = 300
max_volumetric_extrusion_rate_slope_negative = 0
max_volumetric_extrusion_rate_slope_positive = 0
max_volumetric_speed = 0
min_bead_width = 85%
min_fan_speed = 85
min_feature_size = 25%
min_layer_height = 0.07
min_print_speed = 20
min_skirt_length = 4
mmu_segmented_region_max_width = 5
multimaterial_purging = 140
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

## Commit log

2026-09-25 first iteration
    [01_mount_test_black.3mf, 02_skull_faceplate_glow.3mf, 03_carrier_black.3mf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]
2026-09-30 Add compatible shallow sculpted skull faceplate
    [skull_sculpted.3mf, skull_sculpted.step, skull_sculpted.stl]
2026-09-30 Promote prominent sculpted skull as default faceplate
    [02_skull_faceplate_glow.3mf, assembled_bucket.step, bucket_glow.step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]
2026-09-30 adding assembly renders
2026-10-01 final changes
    [03_04_carrier_guard_black.3mf, 03_carrier_black.3mf, assembled_bucket.step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]
